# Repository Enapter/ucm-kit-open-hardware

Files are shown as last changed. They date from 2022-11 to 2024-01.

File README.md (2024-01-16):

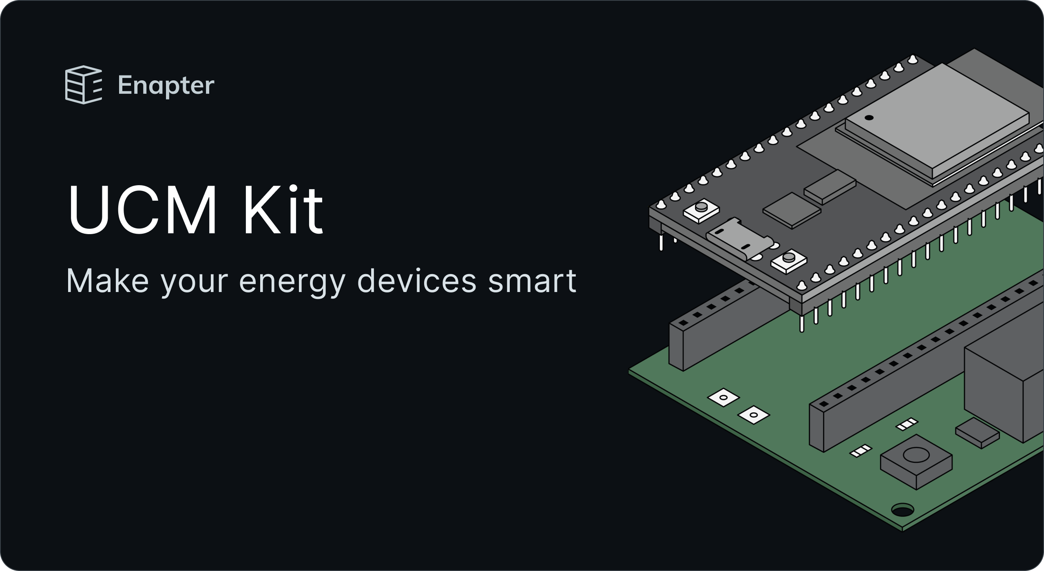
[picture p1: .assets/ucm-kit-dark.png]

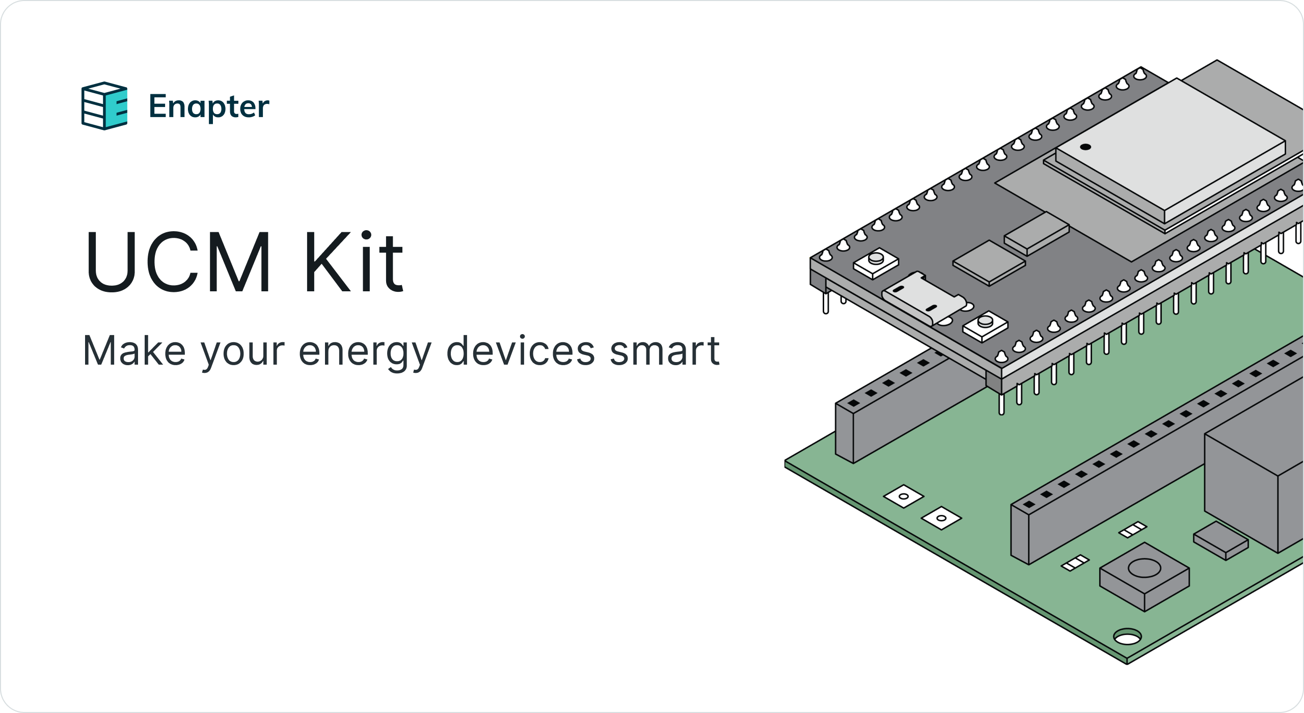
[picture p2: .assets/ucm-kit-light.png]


# What is Enapter UCM Kit

This repository hosts Enapter UCM Kit open hardware documentation for building your own IoT edge devices. It is specially designed for makers, students and researchers to test, learn and teach IoT and Smart Energy.

Enapter UCM Kit based on several important open source and free to use components and provides full-stack IoT technology kit (hardware and software) for rapid development of connected appplications. This opens possibilities for personal technology trials and hardware prototyping. Which is extremely helpful for developing innovative cost-efficient smart energy solutions for emerging markets.

# How to Use

All schematics, CAD files and supplementary materials in this repository are subject of [Solderpad Hardware License v2.1](http://solderpad.org/licenses/SHL-2.1/). Feel free to modify and use for your own projects.

Find more information about Enapter UCM Kit at [Enapter Developer's Portal](https://go.enapter.com/ucmkit-enpkit).

# Release Notes

Check out the [Changelog](./CHANGELOG.md) for the latest updates and release notes.

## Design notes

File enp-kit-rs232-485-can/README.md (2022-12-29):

## ENP-KIT-232-485-CAN

The ENP-KIT-232-485-CAN board is used for demonstrating the capabilities of the Enapter software, implements RS232, RS485, CAN interfaces.

Board was designed in an open-source EDA software <a href="https://www.kicad.org/" target="_blank">KiCad 6.0.</a>

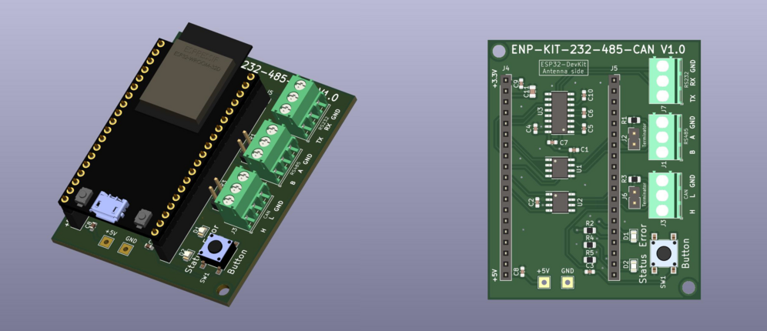
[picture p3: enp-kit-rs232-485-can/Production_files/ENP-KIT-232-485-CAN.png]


| Description | Resource | Note |
| --- | --- | --- |
| Production files | [Full set of docs/files](./Production_files/ENP-KIT-232-485-CAN_V1.0.zip)| ZIP archive |
| Schematic | [ENP-KIT-232-485-CAN](./Production_files/ENP-KIT-232-485-CAN_V1.0_schematic.pdf)  | PDF |
| Quick Start Guide  | Coming soon... | PDF |
| Plastic Enclosure  | <a href="https://www.budind.com/product/general-use-boxes/utilibox-style-j-series-utility-boxes/cu-1941-mb" target="_blank">CU-1941-MB</a> | Plastic box, suitable for this board |
| Where to order for production  | <a href="https://cart.jlcpcb.com/quote?orderType=1&stencilLayer=2&stencilWidth=100&stencilLength=100" target="_blank">jlcpcb.com</a> | You can order the board together with SMT Assembly, there is a separate [archive](./Production_files/jlcpcb_files_V1.0.zip) that includes everything you need |

You also need module:
ESP32-DevKitC-32D and micro USB - USB cable.

Be careful these components are not in the BOM.

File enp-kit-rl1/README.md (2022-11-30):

## ENP-KIT-RL1

The ENP-KIT-RL1 board is used for demonstrating the capabilities of the Enapter software, implements 1 channel normally open relay.

Board was designed in an open-source EDA software <a href="https://www.kicad.org/" target="_blank">KiCad 6.0.</a>

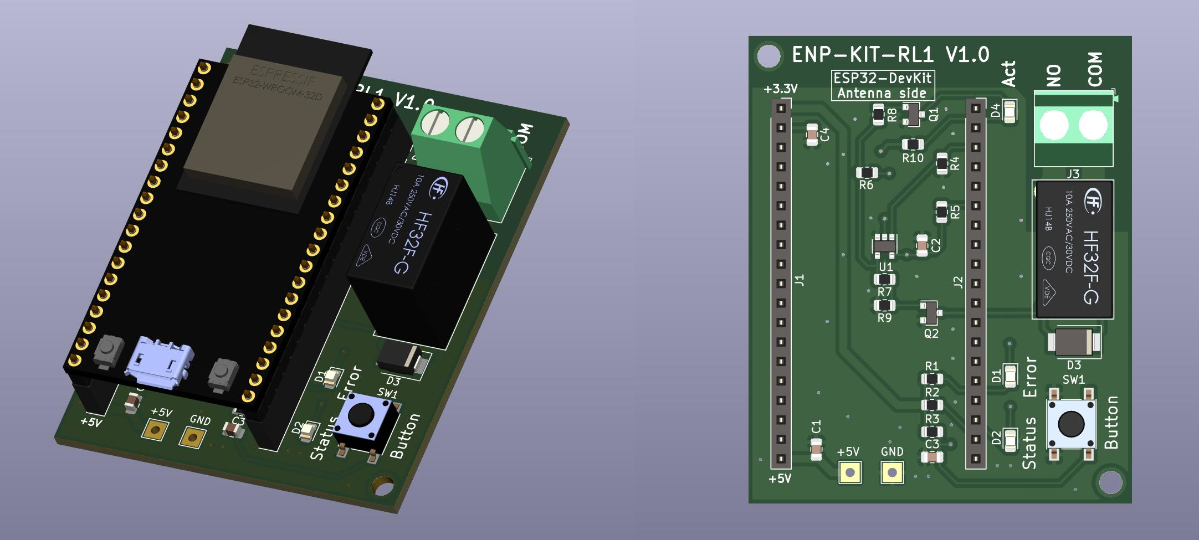
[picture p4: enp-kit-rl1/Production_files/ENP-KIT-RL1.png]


| Description | Resource | Note |
| --- | --- | --- |
| Production files | [Full set of docs/files](./Production_files/ENP-KIT-RL1_V1.0.zip)| ZIP archive |
| Schematic | [ENP-KIT-RL1](./Production_files/ENP-KIT-RL1_V1.0_schematic.pdf)  | PDF |
| Quick Start Guide  | Coming soon... | PDF |
| Plastic Enclosure  | <a href="https://www.budind.com/product/general-use-boxes/utilibox-style-j-series-utility-boxes/cu-1941-mb" target="_blank">CU-1941-MB</a> | Plastic box, suitable for this board |
| Where to order for production  | <a href="https://cart.jlcpcb.com/quote?orderType=1&stencilLayer=2&stencilWidth=100&stencilLength=100" target="_blank">jlcpcb.com</a> | You can order the board together with SMT Assembly, there is a separate [archive](./Production_files/jlcpcb_files_V1.0.zip) that includes everything you need |

You also need module:
ESP32-DevKitC-32D and micro USB - USB cable.

Be careful these components are not in the BOM.

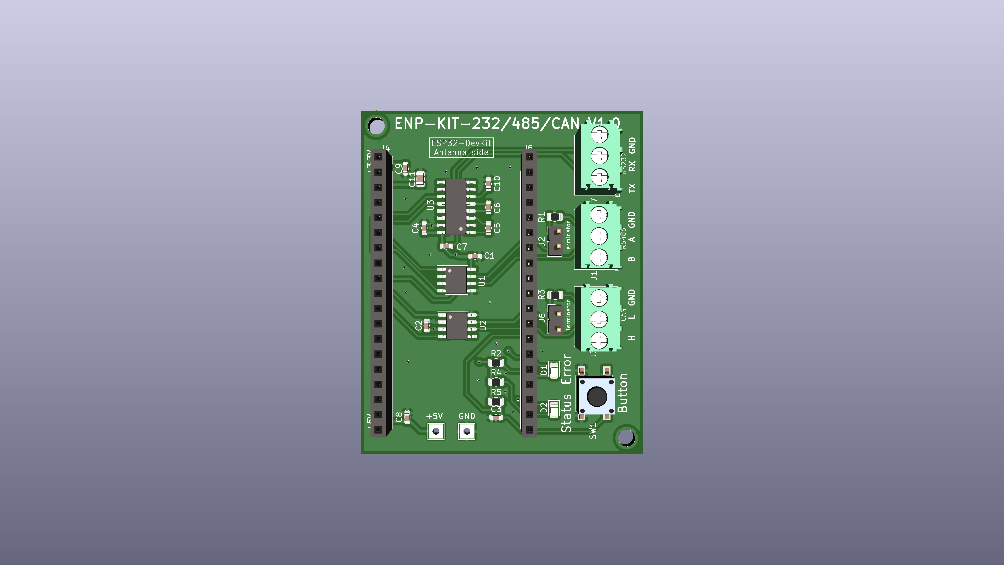
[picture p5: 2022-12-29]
enp-kit-rs232-485-can/Production_files/ENP-KIT-232-485-CAN_.png

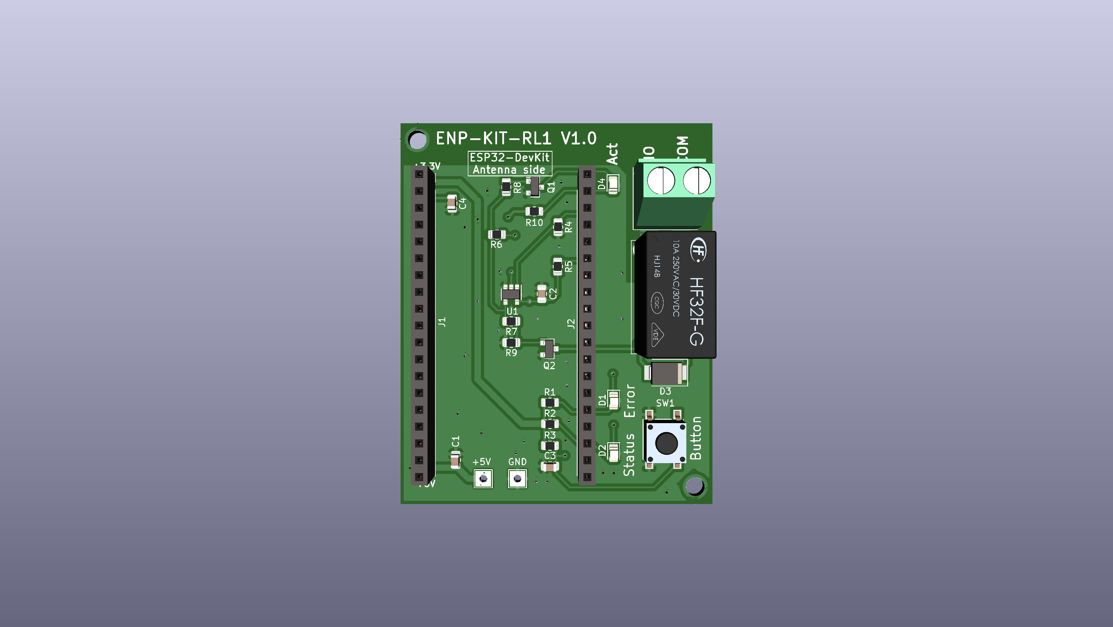
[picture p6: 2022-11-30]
enp-kit-rl1/Production_files/ENP-KIT-RL1_.png

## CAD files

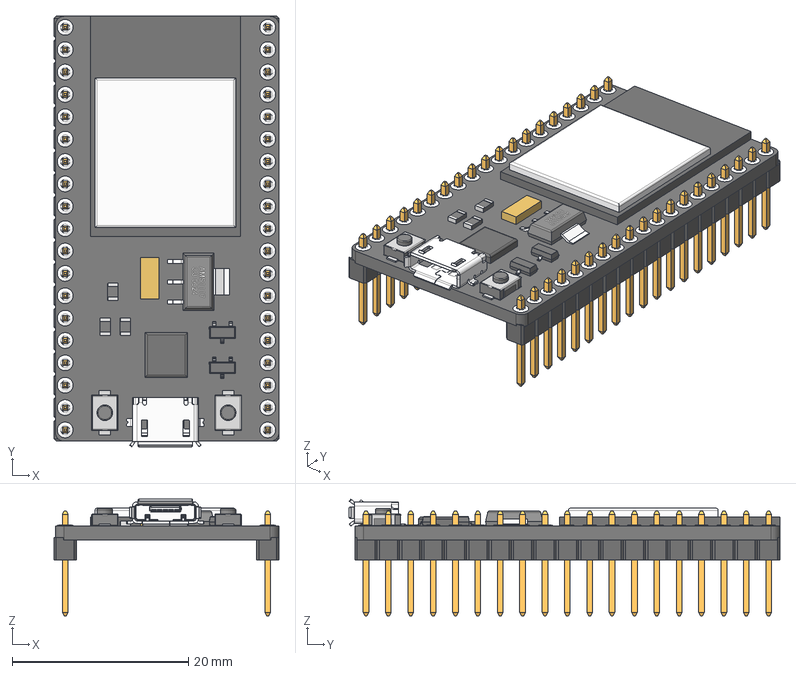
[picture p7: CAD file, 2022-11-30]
enp-kit-rs232-485-can/3d_step/NodeMCU-32S.step
25.5 x 48.9 x 13.3 mm
10104111-0001LF v1
zl201-19_p2-54_l48-3_w2-54_h8-9 v1 x 2
res_0805 v1 x 3
res_1206
AMS1117 v1
SOT23SMD v1 x 2
3x4x2mm - 2 Pad v1 x 2

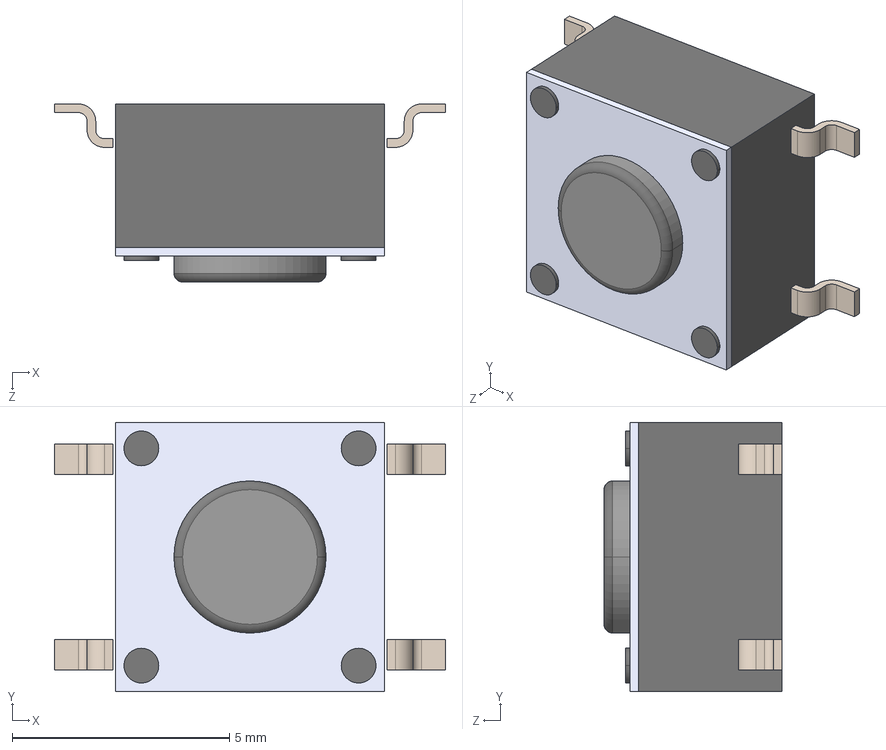
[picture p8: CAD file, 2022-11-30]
enp-kit-rs232-485-can/3d_step/sw_diptronics_dtsm-61r-b.step
9.00 x 6.20 x 4.10 mm

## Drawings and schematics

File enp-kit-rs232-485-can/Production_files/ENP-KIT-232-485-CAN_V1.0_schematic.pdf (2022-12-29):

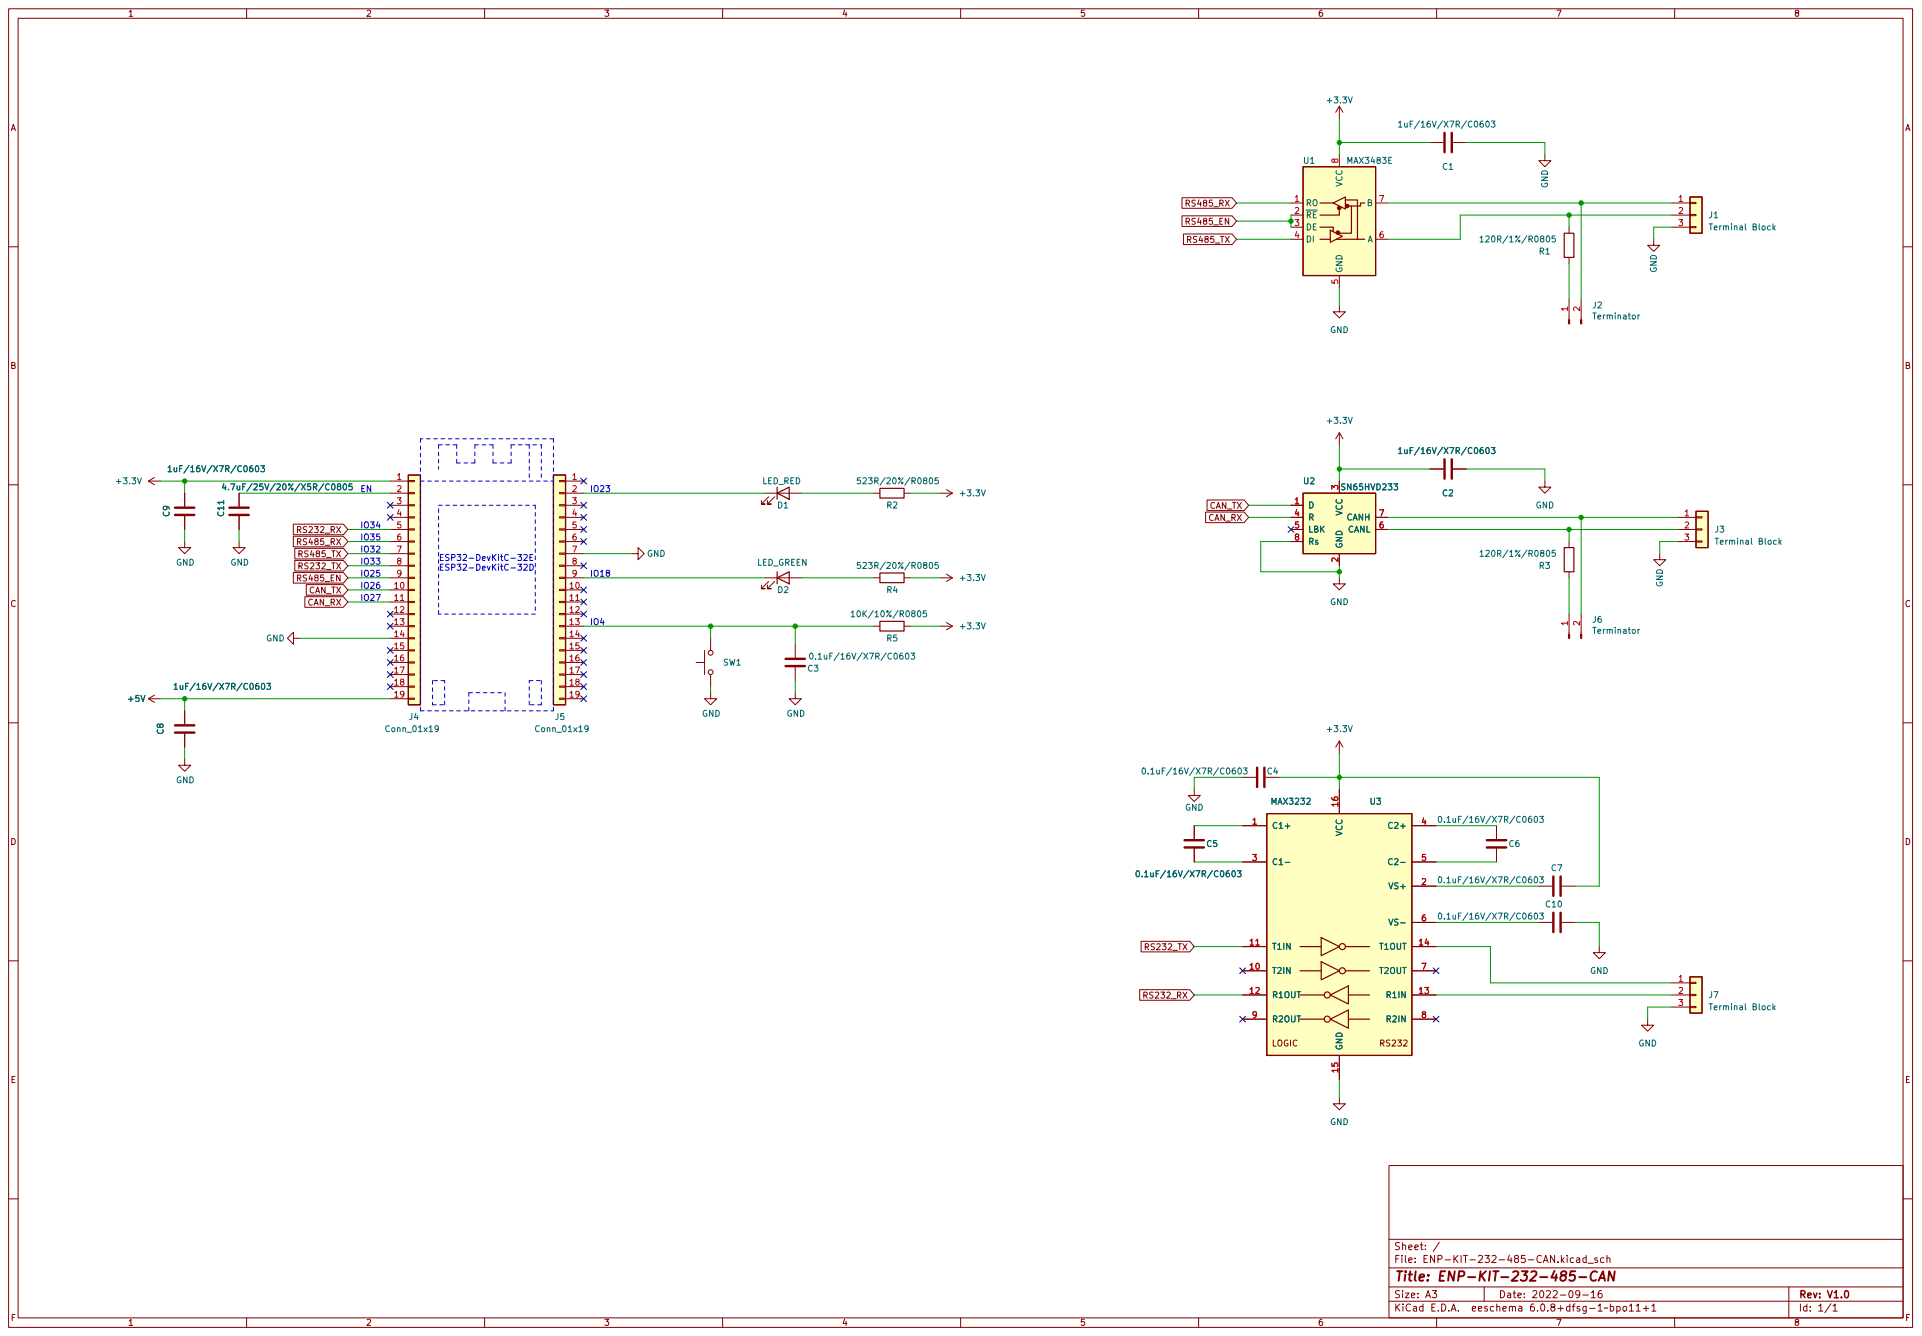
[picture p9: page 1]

File: ENP-KIT-232-485-CAN.kicad_sch Sheet: /
Id: 1/1 Title: ENP-KIT-232-485-CAN

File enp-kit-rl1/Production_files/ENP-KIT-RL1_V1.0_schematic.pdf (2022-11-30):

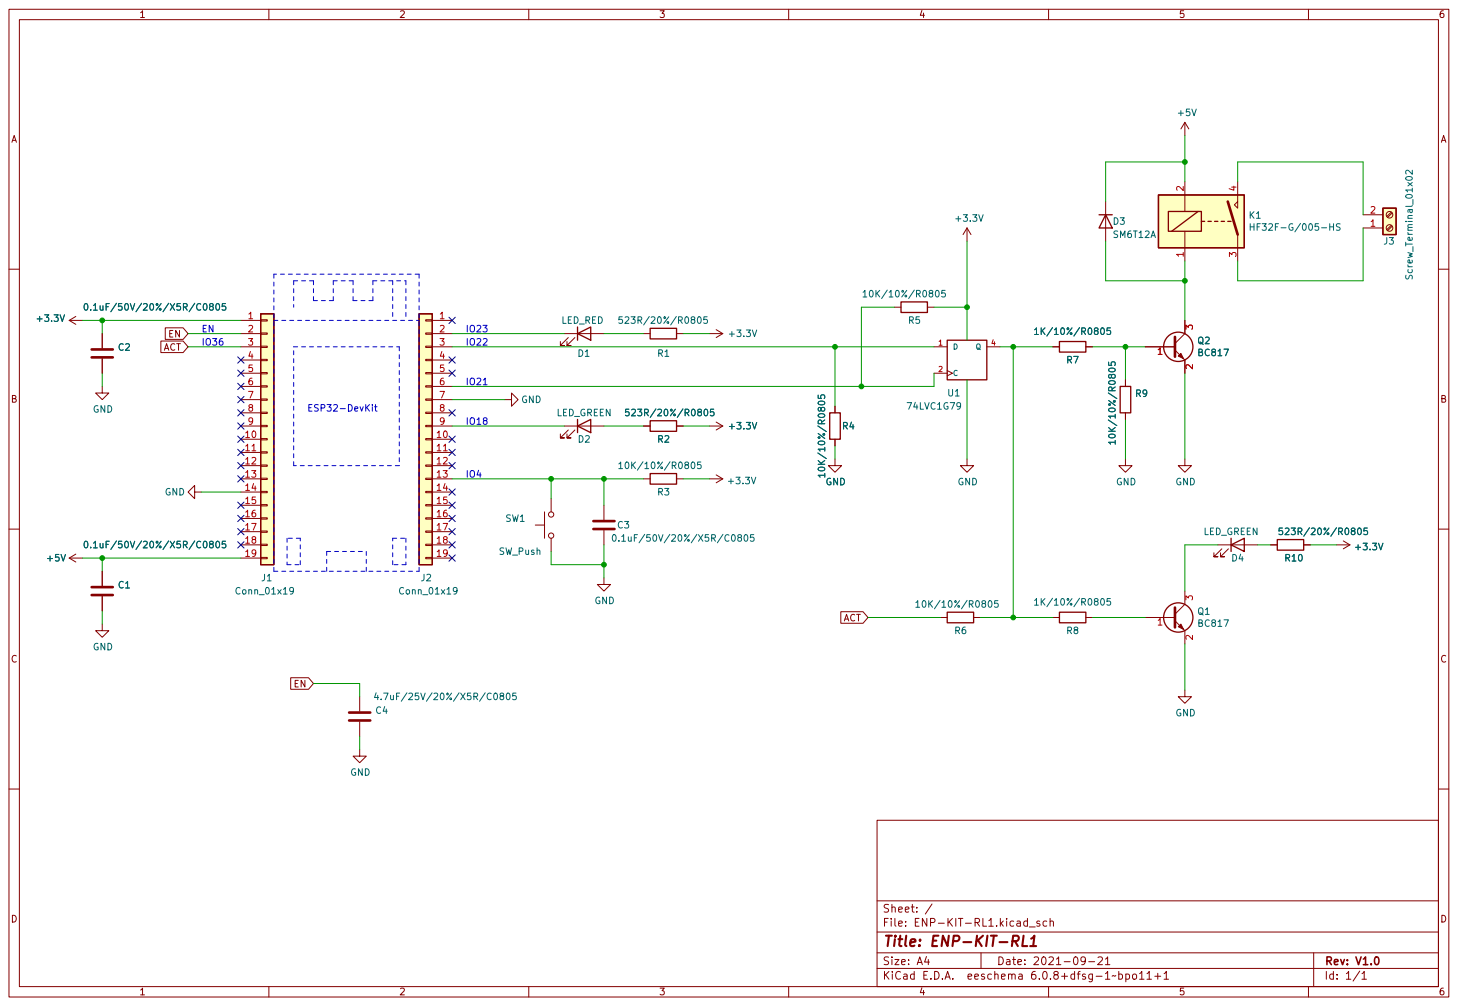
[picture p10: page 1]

File: ENP-KIT-RL1.kicad_sch Sheet: / SW1 SW_Push

Id: 1/1 Title: ENP-KIT-RL1

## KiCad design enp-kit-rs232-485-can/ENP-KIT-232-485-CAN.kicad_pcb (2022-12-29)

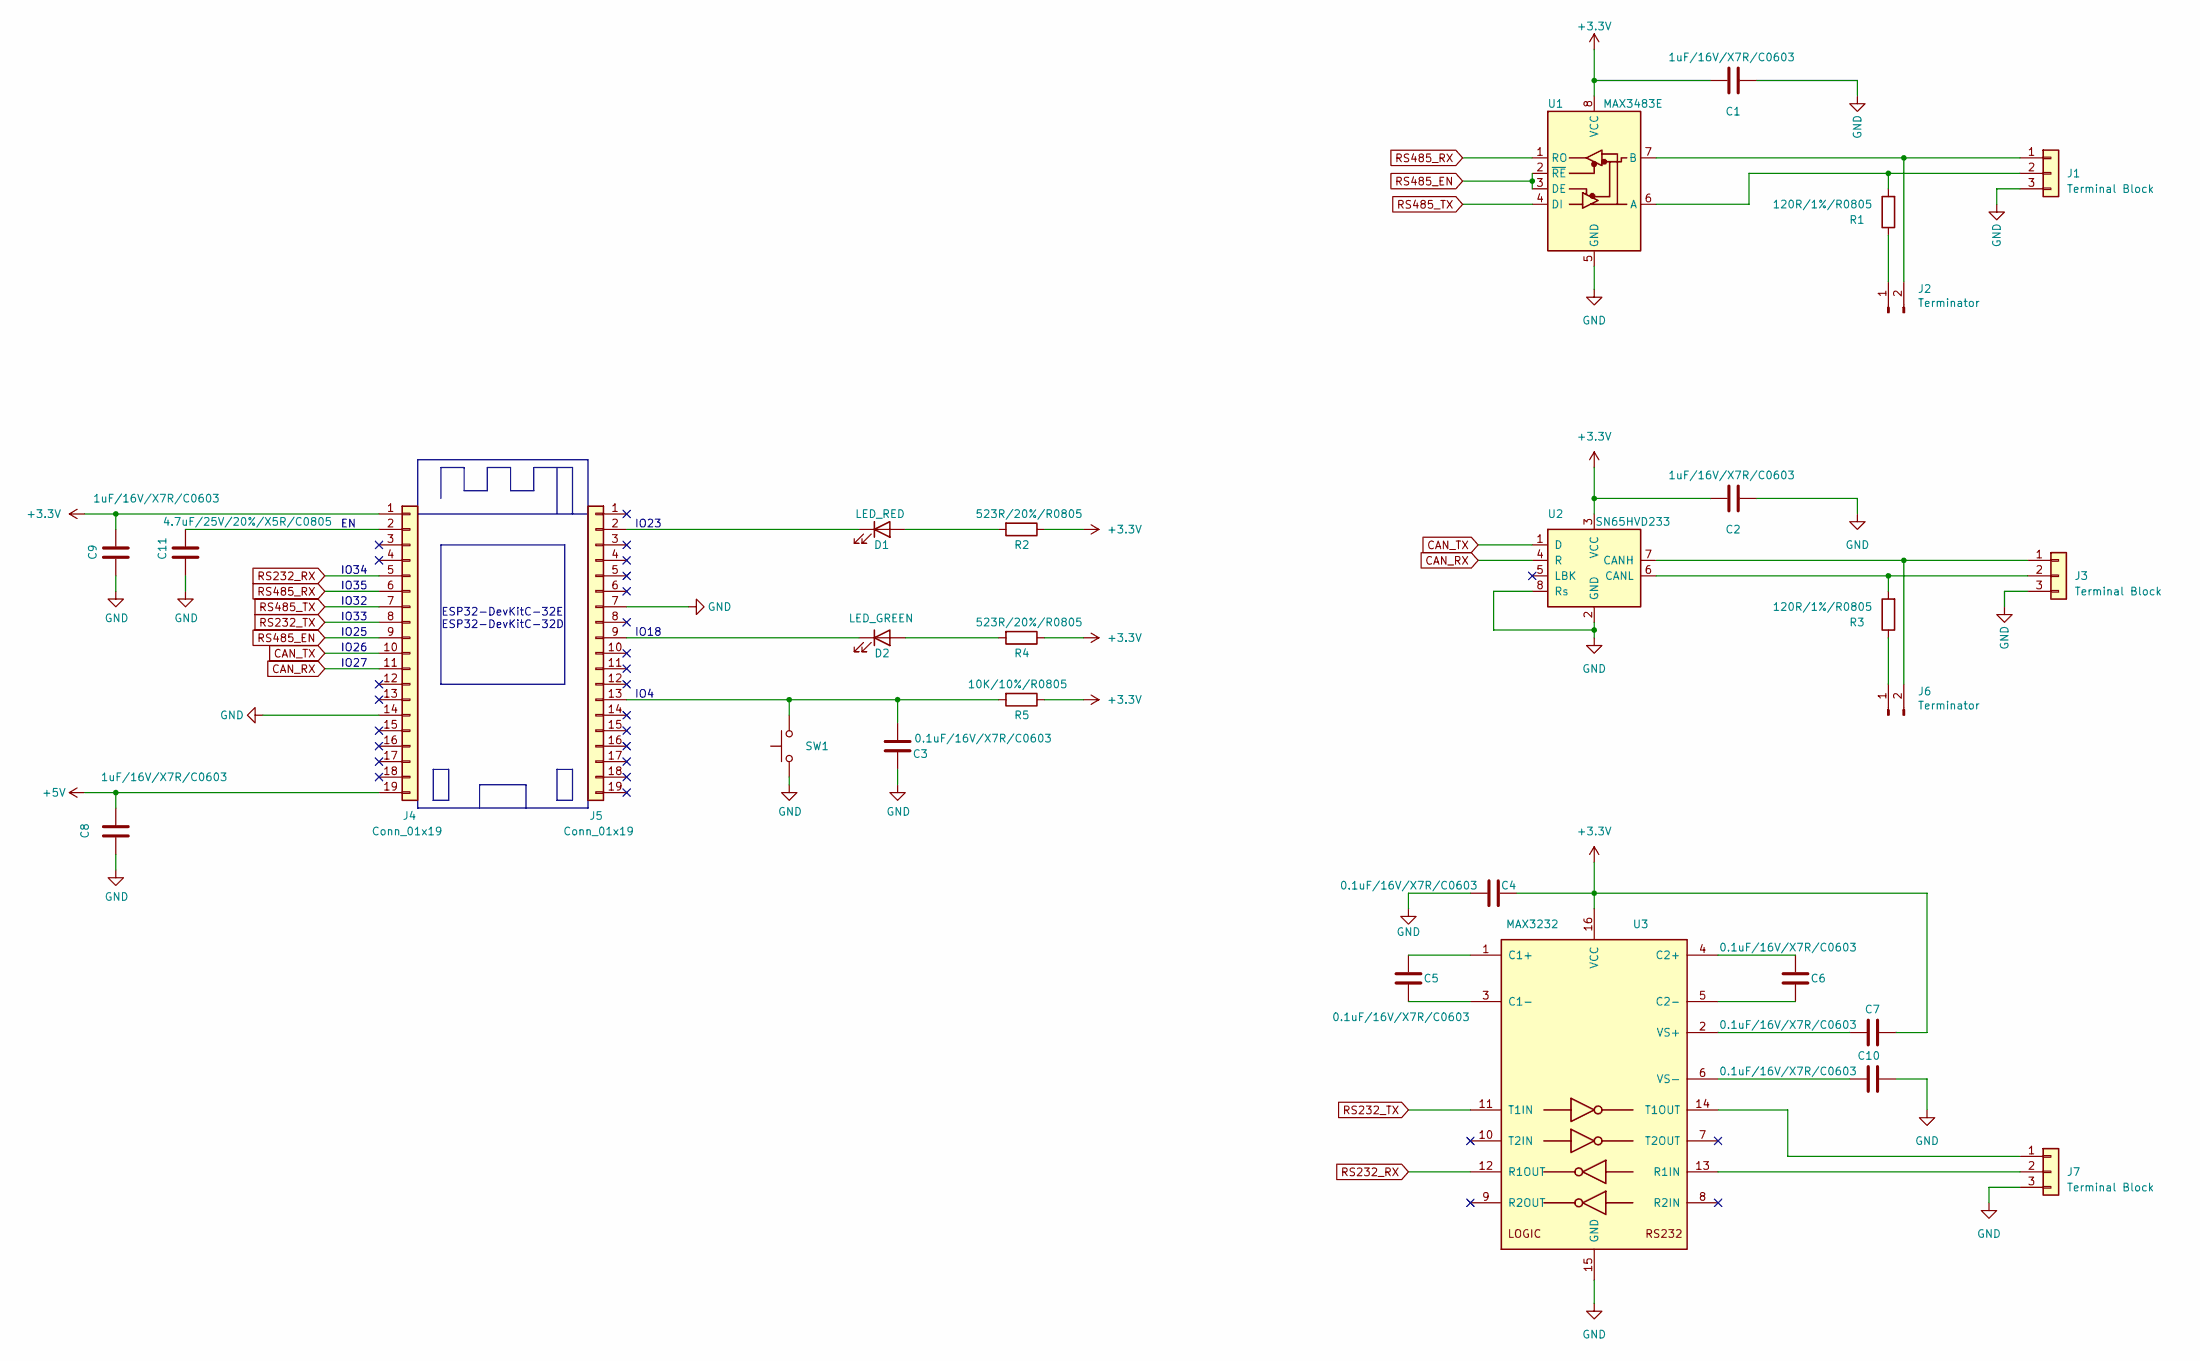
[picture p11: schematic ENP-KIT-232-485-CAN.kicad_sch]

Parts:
C1, C2, C8, C9: 1uF/16V/X7R/C0603; C_0603_1608Metric; Part number CL10A105KB8NNNC; JLCPCB Part # C15849
C3, C4, C5, C6, C7, C10: 0.1uF/16V/X7R/C0603; C_0603_1608Metric; Part number CC0603KRX7R9BB104; JLCPCB Part # C14663
C11: 4.7uF/25V/20%/X5R/C0805; C_0805_2012Metric; Part number CL21A475KAQNNNG; JLCPCB Part # C1779
D1: LED_RED; LED_0805_2012Metric; Part number APT2012SURC; JLCPCB Part # C84256
D2: LED_GREEN; LED_0805_2012Metric; Part number APT2012ZGC; JLCPCB Part # C2297
J1, J3, J7: Terminal Block; TerminalBlock_Phoenix_PT-1,5-3-3.5-H_1x03_P3.50mm_Horizontal; Part number DG350-3.5-03P-14-00A(H); JLCPCB Part # C2760669
J2, J6: Terminator; PinHeader_1x02_P2.54mm_Vertical; Part number DS1021-1*2SF11-B; JLCPCB Part # C492401
J4, J5: Conn_01x19; PinSocket_1x19_P2.54mm_Vertical; Part number PBS-19 (DS1023-1*19SF1); JLCPCB Part # C319202
R1, R3: 120R/1%/R0805; R_0805_2012Metric; Part number RC0805FR-07120RL; JLCPCB Part # C114245
R2, R4: 523R/20%/R0805; R_0805_2012Metric; Part number RC0805FR-07523RL; JLCPCB Part # C218615
R5: 10K/10%/R0805; R_0805_2012Metric; Part number RC0805FR-0710KL; JLCPCB Part # C17414
SW1: SW_Push; SW_Push_1P1T_NO_6x6mm_H9.5mm; Part number DTSM-62Y-V-T/R; JLCPCB Part # C2834922
U1: MAX3483E; SO-8_3.9x4.9mm_P1.27mm; Part number MAX3485EESA+; JLCPCB Part # C668204
U2: SN65HVD233; SOIC-8_3.9x4.9mm_P1.27mm; Part number SN65HVD231DR; JLCPCB Part # C129257
U3: MAX3232; SOIC-16_3.9x9.9mm_P1.27mm; Part number MAX3232ESE+; JLCPCB Part # C2904738

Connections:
+3.3V: C1.1, C2.1, C4.2, C7.2, C9.1, J4.1, R2.1, R4.1, R5.1, U1.8 (VCC), U2.3 (VCC), U3.16 (VCC)
+5V: C8.1, J4.19; also elsewhere on the board
CAN_RX: J4.11, U2.4 (R)
CAN_TX: J4.10, U2.1 (D)
GND: C1.2, C2.2, C3.1, C4.1, C8.2, C9.2, C10.2, C11.2, J1.3, J3.3, J4.14, J5.7, J7.3, SW1.1, U1.5 (GND), U2.2 (GND), U2.8 (Rs), U3.15 (GND); also elsewhere on the board
unnamed: C3.2, J5.13, R5.2, SW1.2
unnamed: C5.1, U3.3 (C1-)
unnamed: C5.2, U3.1 (C1+)
unnamed: C6.1, U3.5 (C2-)
unnamed: C6.2, U3.4 (C2+)
unnamed: C7.1, U3.2 (VS+)
unnamed: C10.1, U3.6 (VS-)
unnamed: D1.1 (K), J5.2
unnamed: D1.2 (A), R2.2
unnamed: D2.1 (K), J5.9
unnamed: D2.2 (A), R4.2
unnamed: J1.1, J2.2, U1.7 (B)
unnamed: J1.2, R1.2, U1.6 (A)
unnamed: J2.1, R1.1
unnamed: J3.1, J6.2, U2.7 (CANH)
unnamed: J3.2, R3.2, U2.6 (CANL)
unnamed: C11.1, J4.2
unnamed: J6.1, R3.1
unnamed: J7.1, U3.14 (T1OUT)
unnamed: J7.2, U3.13 (R1IN)
RS232_RX: J4.5, U3.12 (R1OUT)
RS232_TX: J4.8, U3.11 (T1IN)
RS485_EN: J4.9, U1.2 (~RE), U1.3 (DE)
RS485_RX: J4.6, U1.1 (RO)
RS485_TX: J4.7, U1.4 (DI)

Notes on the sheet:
IO4
IO35
IO26
IO27
IO18
ESP32-DevKitC-32E ESP32-DevKitC-32D
IO32
IO34
IO33
IO23
IO25

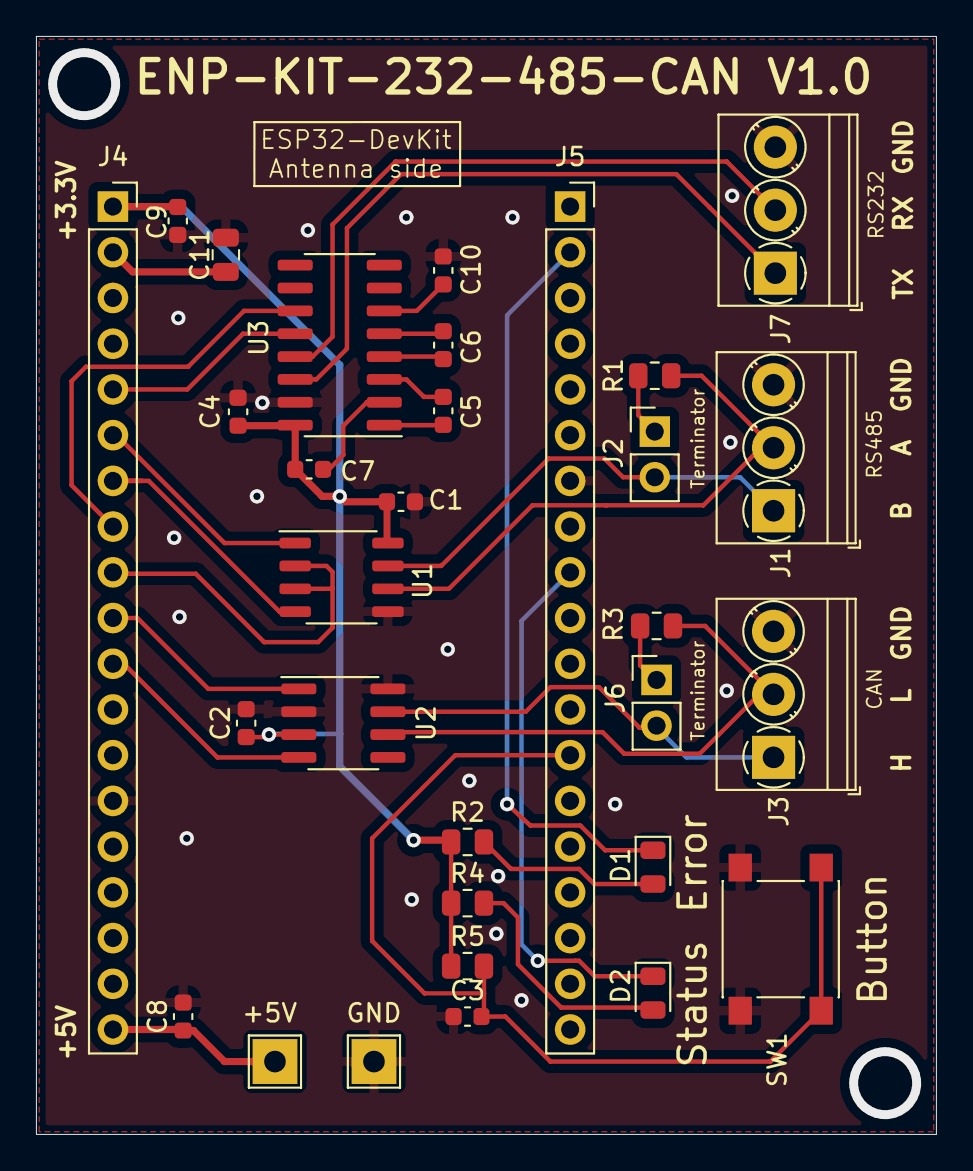
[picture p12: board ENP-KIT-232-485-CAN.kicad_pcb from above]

Board: 2 copper layers, 50.0 x 61.0 mm, 31 parts (0 on the bottom side), 30 nets.

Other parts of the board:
+5V: TestPoint_THTPad_2.5x2.5mm_Drill1.2mm
GND: TestPoint_THTPad_2.5x2.5mm_Drill1.2mm

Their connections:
+5V: +5V.1; also elsewhere on the board
GND: GND.1; also elsewhere on the board

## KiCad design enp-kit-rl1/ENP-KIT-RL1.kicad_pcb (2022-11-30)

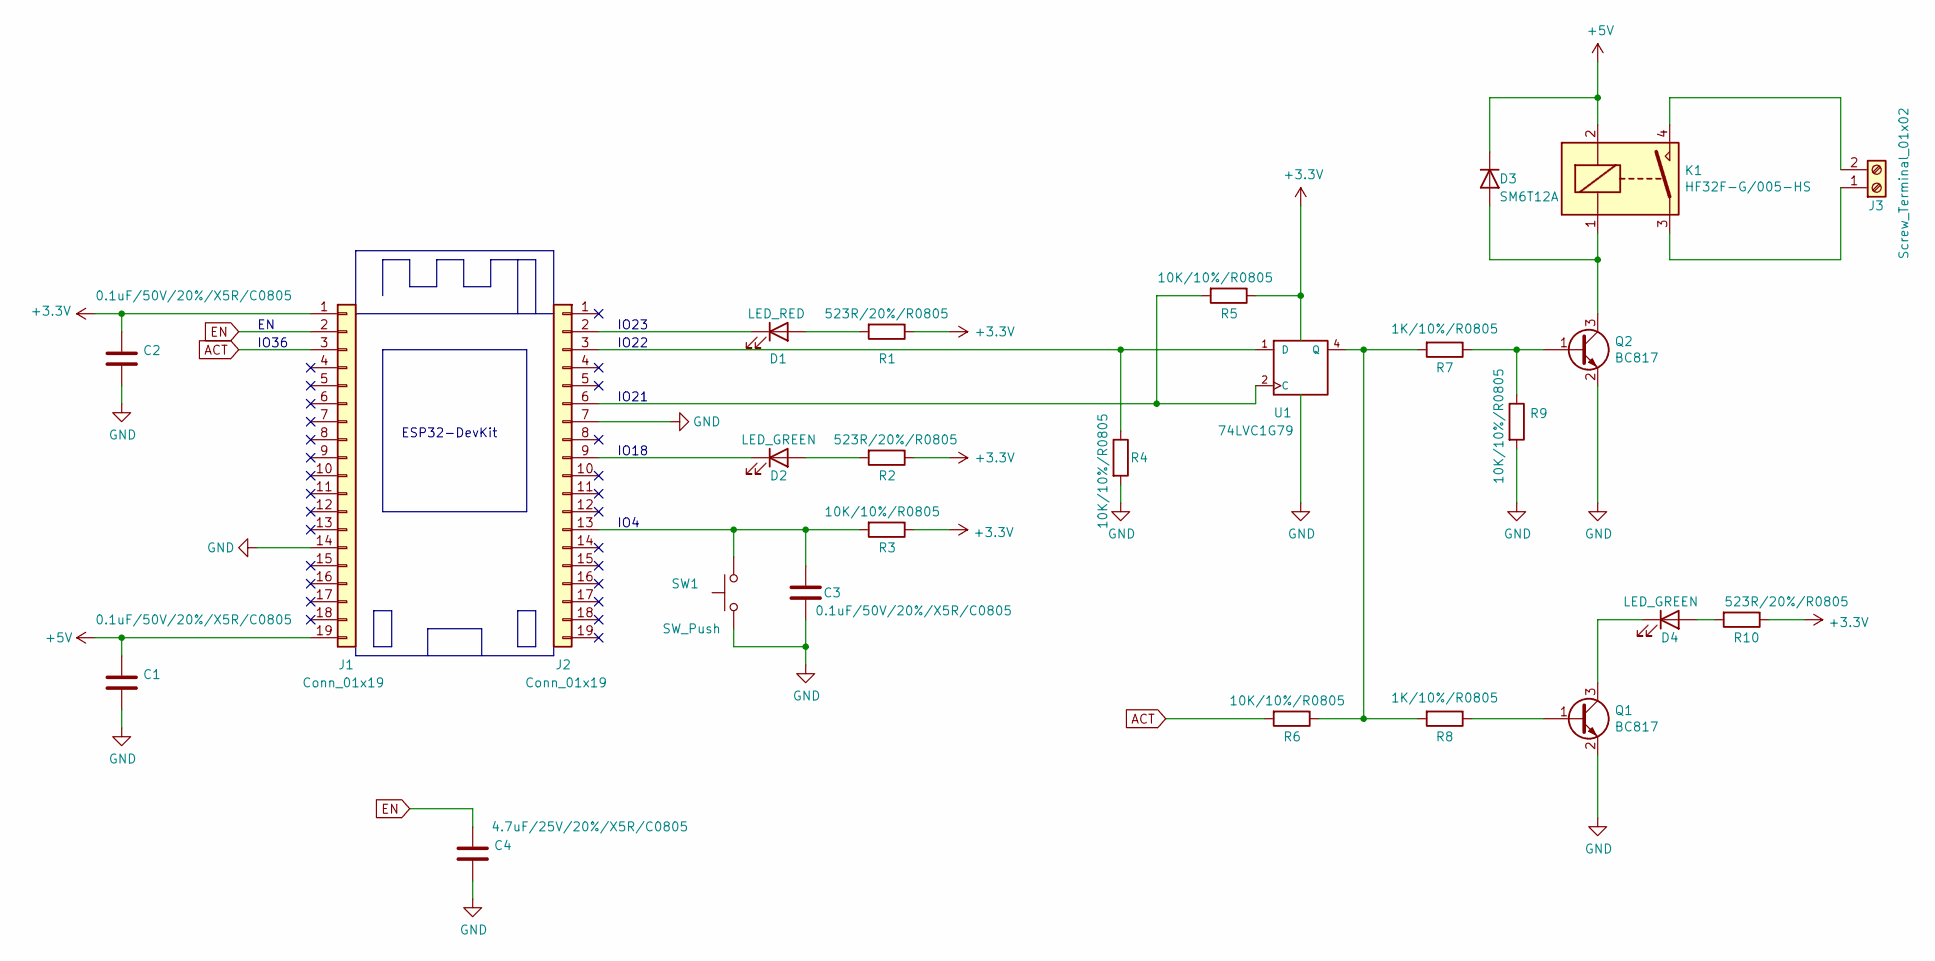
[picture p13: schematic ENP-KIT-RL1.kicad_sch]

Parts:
C1, C2, C3: 0.1uF/50V/20%/X5R/C0805; C_0805_2012Metric; Part number C0805C104M5RACTU; JLCPCB Part # C286511
C4: 4.7uF/25V/20%/X5R/C0805; C_0805_2012Metric; Part number CL21A475KAQNNNG; JLCPCB Part # C1779
D1: LED_RED; LED_0805_2012Metric; Part number APT2012SURC; JLCPCB Part # C84256
D2, D4: LED_GREEN; LED_0805_2012Metric; Part number APT2012ZGC; JLCPCB Part # C2297
D3: SM6T12A; D_SMB; Part number SM6T12A; JLCPCB Part # C113981
J1, J2: Conn_01x19; PinSocket_1x19_P2.54mm_Vertical; Part number PBS-19 (DS1023-1*19SF1); JLCPCB Part # C319202
J3: Screw_Terminal_01x02; TerminalBlock_Phoenix_MKDS-1,5-2-5.08_1x02_P5.08mm_Horizont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; Part number DG500-5.08-02P-14-00A(H); JLCPCB Part # C691859
K1: HF32F-G/005-HS; HF32F-G; Part number HF32F-G/005-HS; JLCPCB Part # C74541
Q1, Q2: BC817; SOT-23; Part number BC817-16,215; JLCPCB Part # C118725
R1, R2, R10: 523R/20%/R0805; R_0805_2012Metric; Part number RC0805FR-07523RL; JLCPCB Part # C218615
R3, R4, R5, R6, R9: 10K/10%/R0805; R_0805_2012Metric; Part number RC0805FR-0710KL; JLCPCB Part # C17414
R7, R8: 1K/10%/R0805; R_0805_2012Metric; Part number RC0805FR-071KL; JLCPCB Part # C269744
SW1: SW_Push; SW_Push_1P1T_NO_6x6mm_H9.5mm; Part number DTSM-62Y-V-T/R; JLCPCB Part # C2834922
U1: 74LVC1G79; SOT-23-5; Part number SN74LVC1G79DBV; JLCPCB Part # C42878

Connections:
+3V3: C2.1, J1.1, R1.1, R2.1, R3.1, R5.1, R10.1, U1.5 (VCC)
+5V: C1.1, D3.1 (K), J1.19, K1.2; also elsewhere on the board
ACT: J1.3, R6.2
EN: C4.1, J1.2
GND: C1.2, C2.2, C3.1, C4.2, J1.14, J2.7, Q1.2 (E), Q2.2 (E), R4.2, R9.2, SW1.1, U1.3 (GND); also elsewhere on the board
unnamed: C3.2, J2.13, R3.2, SW1.2
unnamed: D1.1 (K), J2.2
unnamed: D1.2 (A), R1.2
unnamed: D2.1 (K), J2.9
unnamed: D2.2 (A), R2.2
unnamed: D3.2 (A), K1.1, Q2.3 (C)
unnamed: D4.1 (K), Q1.3 (C)
unnamed: D4.2 (A), R10.2
unnamed: J2.3, R4.1, U1.1 (D)
unnamed: J2.6, R5.2, U1.2 (C)
unnamed: J3.1, K1.3
unnamed: J3.2, K1.4
unnamed: Q1.1 (B), R8.1
unnamed: Q2.1 (B), R7.1, R9.1
unnamed: R6.1, R7.2, R8.2, U1.4 (Q)

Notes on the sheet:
IO18
IO23
IO21
IO22
IO36
ESP32-DevKit
IO4

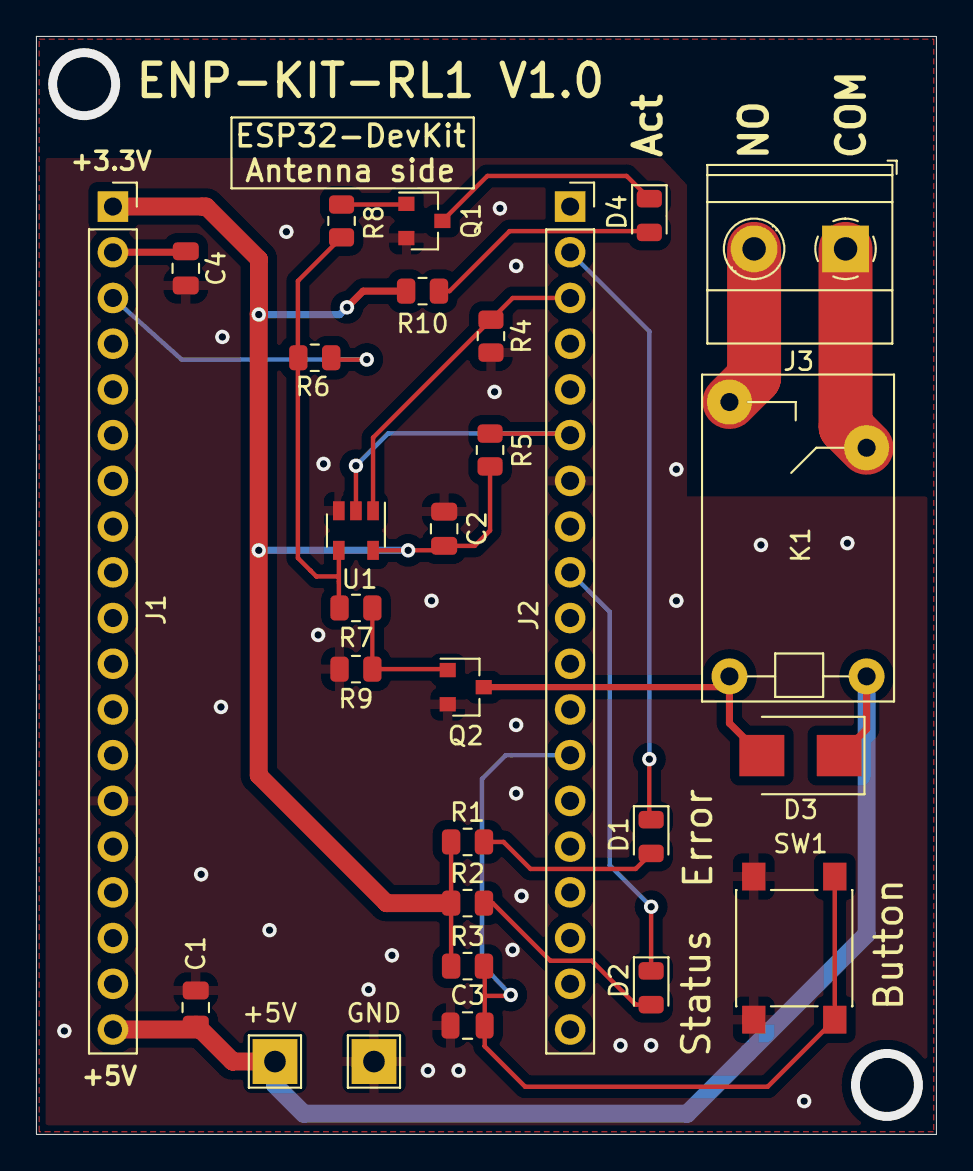
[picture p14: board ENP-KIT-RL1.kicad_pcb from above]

Board: 2 copper layers, 50.0 x 61.0 mm, 28 parts (0 on the bottom side), 20 nets.

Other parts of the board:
+5V: TestPoint_THTPad_2.5x2.5mm_Drill1.2mm
GND: TestPoint_THTPad_2.5x2.5mm_Drill1.2mm

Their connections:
+5V: +5V.1; also elsewhere on the board
GND: GND.1; also elsewhere on the board

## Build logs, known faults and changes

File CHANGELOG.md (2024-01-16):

## V1.0 (December 1, 2022)
Initial release.

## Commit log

2022-11-01 ENP-KIT-RL1 initial commit
    [enp-kit-rl1_JLCPCB_bom.csv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]
2022-11-22 UCM kit rl1 refactor
    [enp-kit-rl1_JLCPCB_bom.csv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]
2022-11-28 add kicad project sources
    [ENP-KIT-RL1.kicad_pcb, ENP-KIT-RL1.kicad_sch, NodeMCU-32S.step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]
2022-11-28 remove html bom section
2022-12-01 add enp-serial kit
    [ENP-KIT-232-485-CAN.kicad_pcb, ENP-KIT-232-485-CAN.kicad_sch, NodeMCU-32S.step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]
